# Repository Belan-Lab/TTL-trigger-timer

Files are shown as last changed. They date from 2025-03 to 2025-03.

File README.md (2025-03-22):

General Purpose TTL Timer
===========

TTL trigger timer for working with light sources for animal behavioral tests.

_Protocol written by Valeriia Ustymenko_

## Operation

```
Keypad schematic:

       |3|
|1| |2|    |5|
       |4|
```

__1__ - Emergency stop

__2__ - Time setting mode (1.0s or 0.1s)

__3__ - Increase time

__4__ - Decrease time

__5__ - Timer start/stop

The push button works the same as button 5: 1 press to start, 2 presses to stop.

Press button 5 to reset the timer between measurements.

## Preparation of the system for tests
For optogenetic tests, a system in such configuration was as pictured in the figure below: 

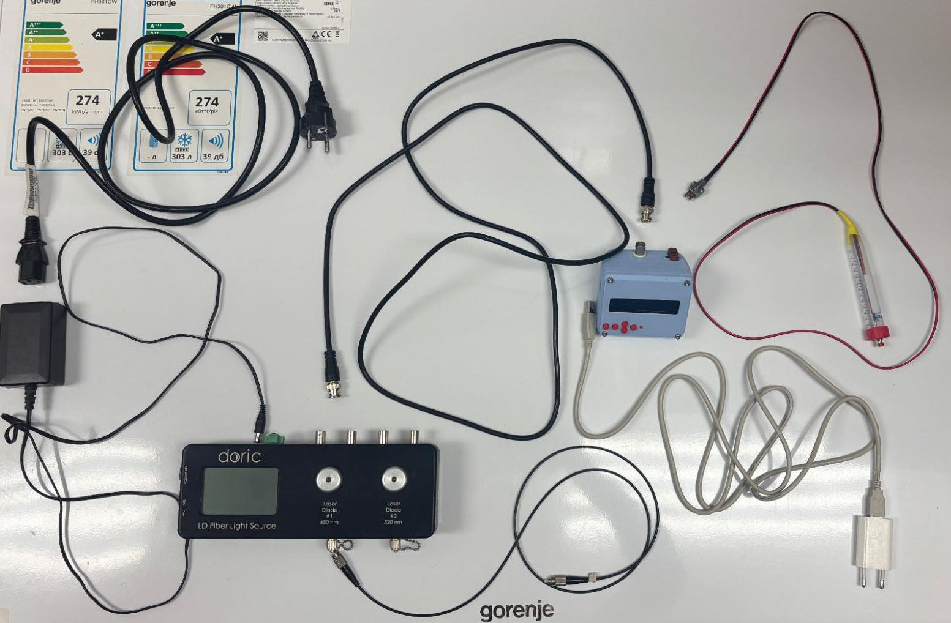
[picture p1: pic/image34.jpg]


*All equipment, needed for optogenetic test*

1. The Doric LDFLS_450/075_520/060 requires a 12V DC power supply. Plug in a cable in the power adapter for the laser diode fiber light source (Doric, LDFLS_450/075_520/060).
2. Locate the 12V DC power input on the back or side of the laser diode fiber light source (Doric, LDFLS_450/075_520/060).
3. Use a BNC cable to connect the TTL signal source to the laser's TTL input for laser diode #1, 450 nm. Rotate the connector to ensure that it is properly secured.

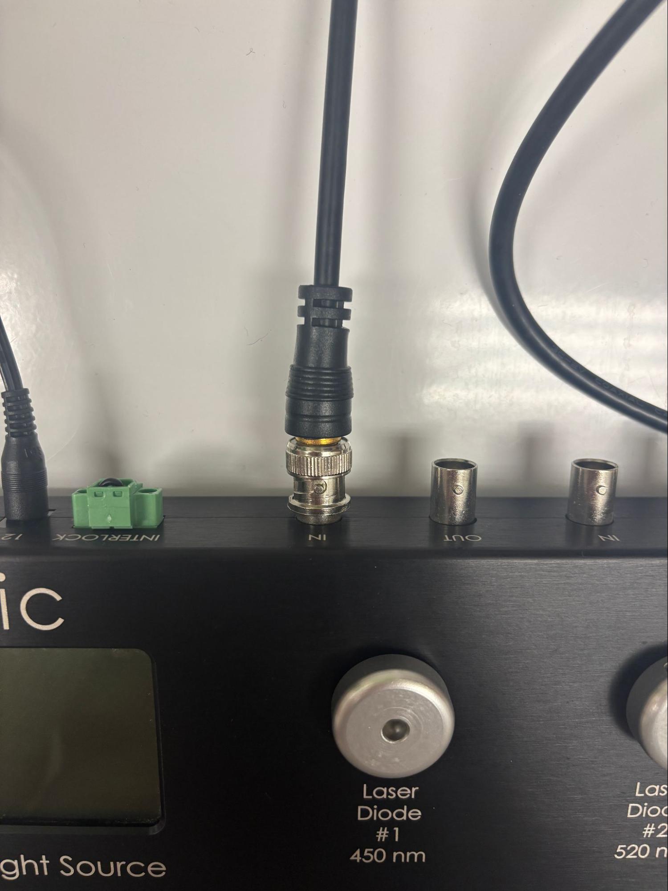
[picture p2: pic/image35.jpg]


4. Check for dust or debris on the fiber tip of optical fiber. Align the fiber connector with the 450 nm laser output port. Gently insert the fiber into the port without forcing it. Rotate clockwise until snug. Do not overtighten, as this can damage the fiber or connector.

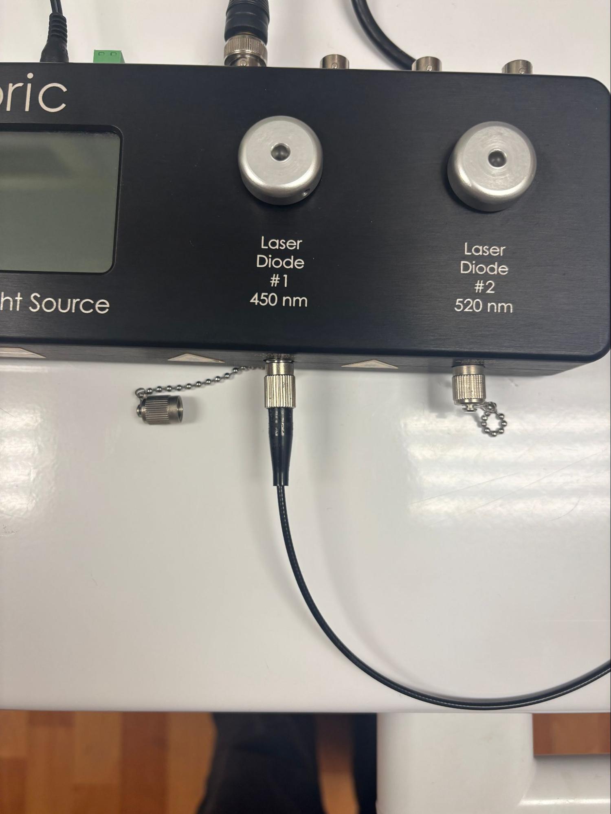
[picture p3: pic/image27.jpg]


__Note: Detailed description of the Doric LDFLS setup is not provided here!__

5. Use a BNC cable to connect the the laser's TTL input for laser diode #1, 450 nm to the TTL timer (Arduino-UNO compatible board with LCD-keypad shield in a very beautiful blue plastic box!). Ensure that you properly secure it by rotating the connector.

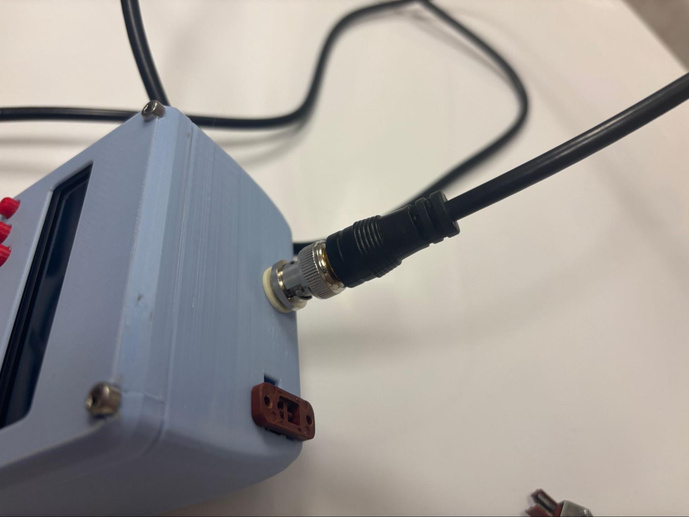
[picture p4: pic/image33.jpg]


6. Plug in a cable that connects the TTL timer  to a push button mounted on a 15 mL centrifuge tube.

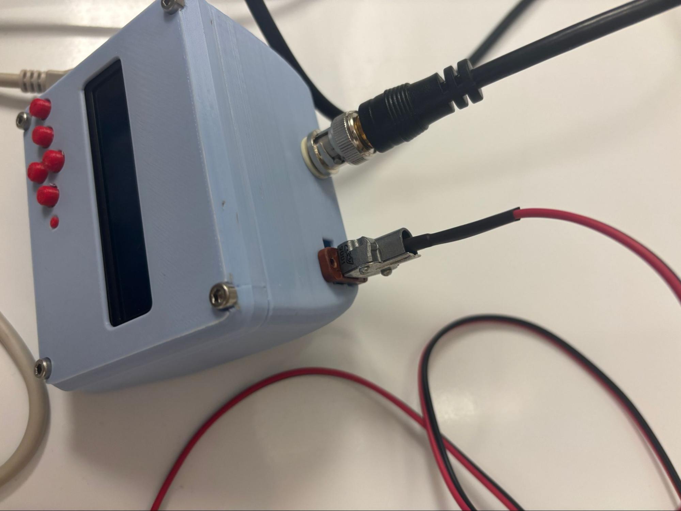
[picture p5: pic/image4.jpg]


7. Plug a DC power adapter into the Arduino’s power jack. The power LED on the Arduino should turn on. Use a regulated power supply to prevent damage. 

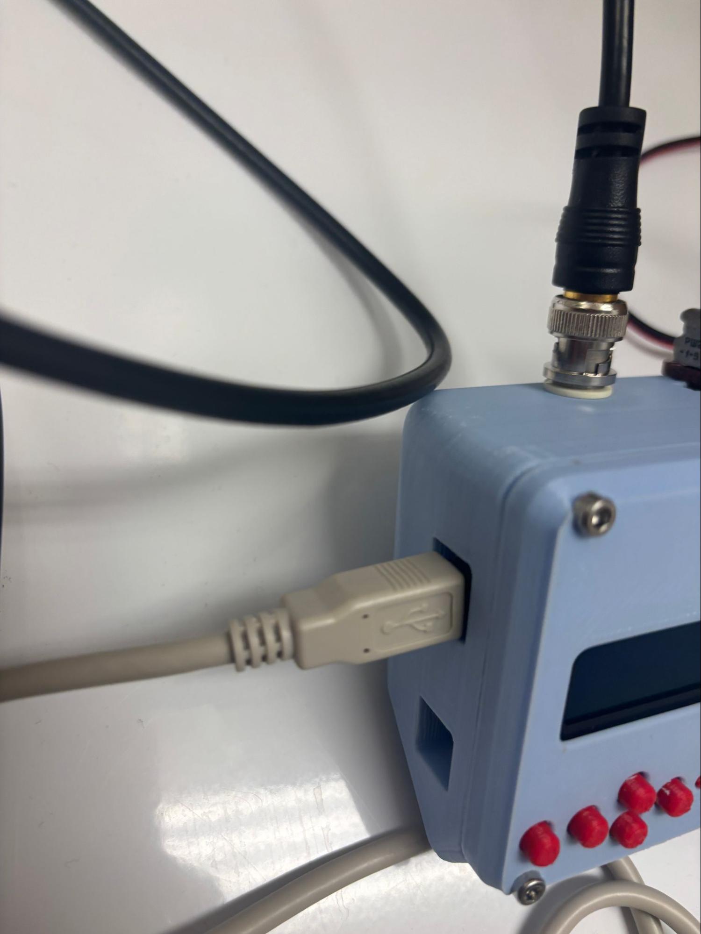
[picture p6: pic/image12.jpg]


8. Set a mode on the TTL timer by pushing the second red button from the left. Two main modes differ in such a way: 1.0 s mode allows to set max explosion time by seconds, and 0.1s mode - 100 milliseconds. 

| 1.0s Mode | 0.1s Mode |
| :---: | :---: |
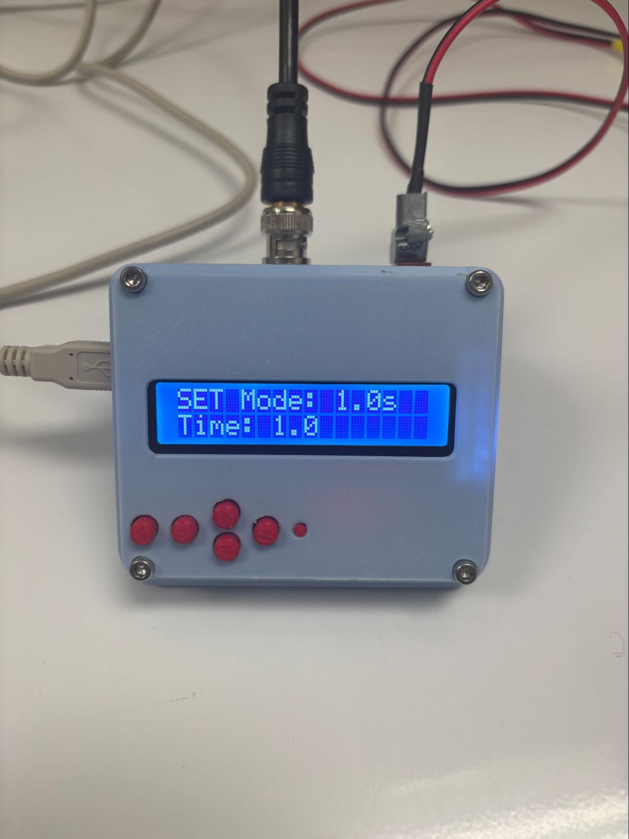
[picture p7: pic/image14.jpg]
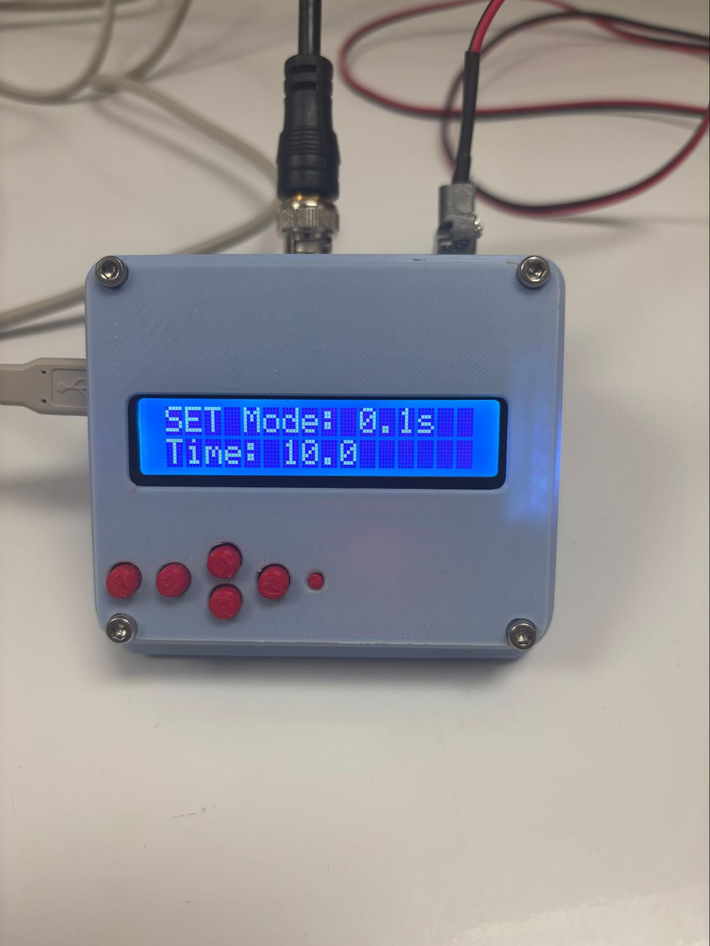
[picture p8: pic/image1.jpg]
|  |  |

10. Set the max time of exposing the hind paw by pushing the third buttons from the left, or middle buttons. We choose max one second exposition to prevent misinterpretation due to thermal stimulation rather than optical activation. The minimal possible exposition is 0.2 seconds.

11. Check the correctness of working of all components of the system by pushing a push button mounted on a 15 mL vial. Do not orient the laser to the eyes!

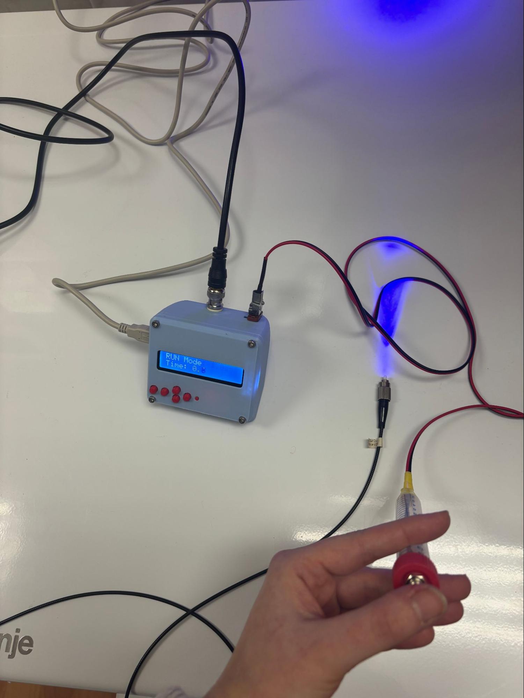
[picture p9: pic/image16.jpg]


-----

## STL Models
The following models from open sources were used in this project:

- [Case for Arduino Uno, LCD Keypad Shield and Stepper Motor Driver by AndreySamokhin on Thingiverse](https://www.thingiverse.com/thing:4194107)
- [Arduino UNO Case](https://www.printables.com/model/244590-arduino-uno-case-with-m3-screwsnuts-and-hexagonal-) and [LCD Keypad Shield Case](https://www.printables.com/model/244258-arduino-lcd-keypad-shield-snap-fit-case) from [@jacek on Printables](https://www.printables.com/@jacek)

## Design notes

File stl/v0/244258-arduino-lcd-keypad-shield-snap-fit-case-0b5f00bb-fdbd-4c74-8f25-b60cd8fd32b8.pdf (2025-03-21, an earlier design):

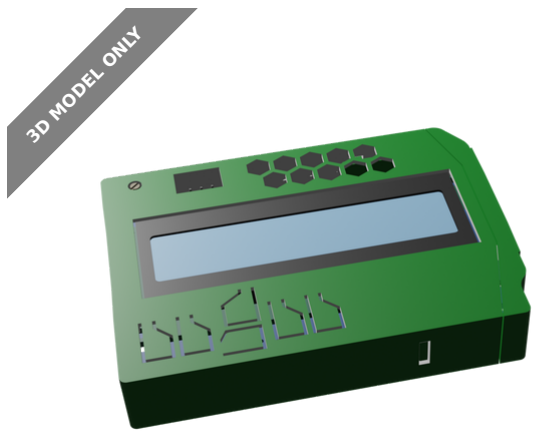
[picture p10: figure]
3D MODEL ONLY

### Summary

Case for Arduino LCD Keypad Shield. Two parts that snap-fit together, integrated buttons.

Hobby & Makers (https://www.printables.com/model?categoryId=48) > Electronics (https://www.printables.com/model?categoryId=52)

Tags: case | shield | arduino | snap | snapfit | lcd | keypad

keypadshield

I made a case for LCD Keypad shield for arduino uno.

The case holds on to the shield itself, so the shield can be detached from arduino togather with case.

The buttons are integrated in the case itself (similar to reset button on prusa printers), so no small parts that fall out during assembly.

Print both parts, orient it flat on the print bed in slicer (front face at the bottom).

Activate supports - activate “Supports on build plate only”.

Works well with my arduino case.

jacek (https://www.printables.com/social/214001/about)

### Arduino LCD

## Keypad Shield

### Snap-Fit case

VIEW IN BROWSER (https://www.printables.com/model/244258-arduino-lcd-keypad-shield-snap-fit-case)

updated 18. 7. 2022 | published 18. 7. 2022

## Model files

### License

This work is licensed under a
Creative Commons (4.0 International License)

Attribution (http://creativecommons.org/licenses/by/4.0/)

✖ | Sharing without ATTRIBUTION
✔ | Remix Culture allowed
✔ | Commercial Use
✔ | Free Cultural Works
✔ | Meets Open Definition

lcd_keypad_shield_case_bighalf_v2.stl

lcd_keypad_shield_case_cover_v2.stl

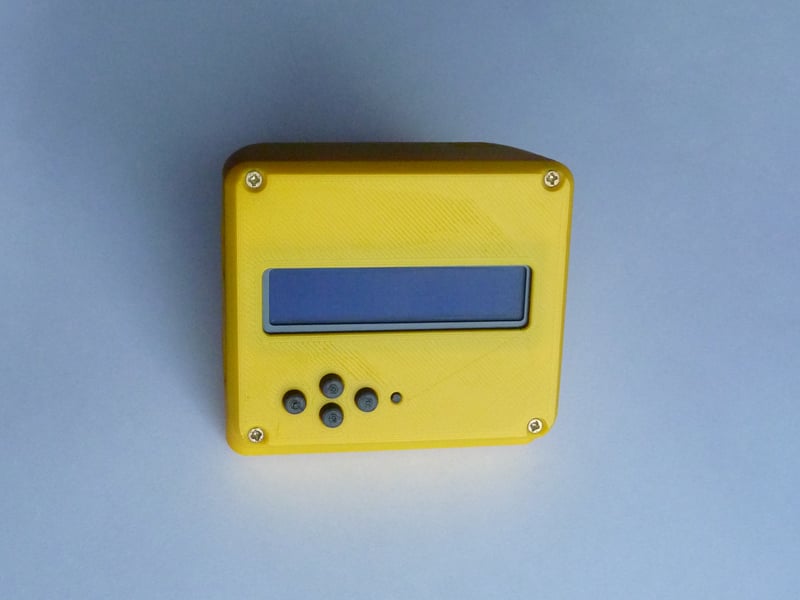
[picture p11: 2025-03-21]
stl/v2/images/fig5.jpg

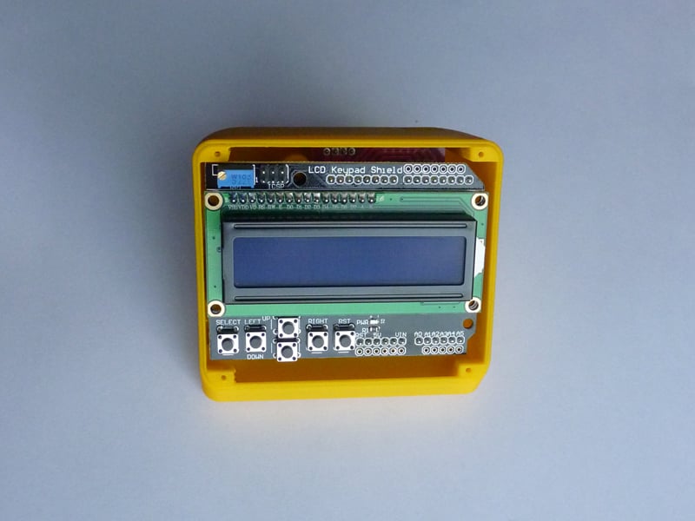
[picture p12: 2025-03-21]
stl/v2/images/fig4.jpg

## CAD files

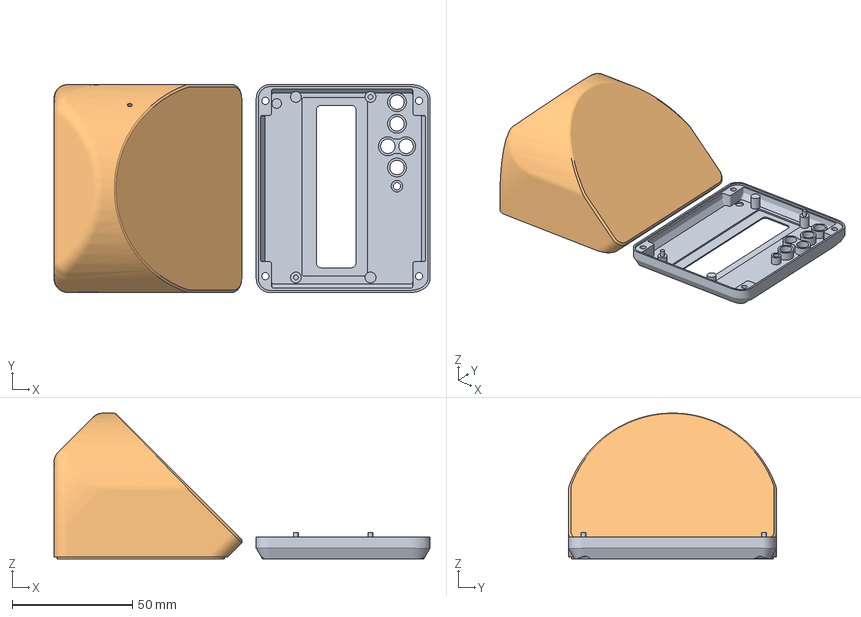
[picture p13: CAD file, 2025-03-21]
stl/v2/caseСover_6buttons.3mf
156.2 x 86.5 x 60.6 mm
caseСover_6buttons.stl
caseBase.stl

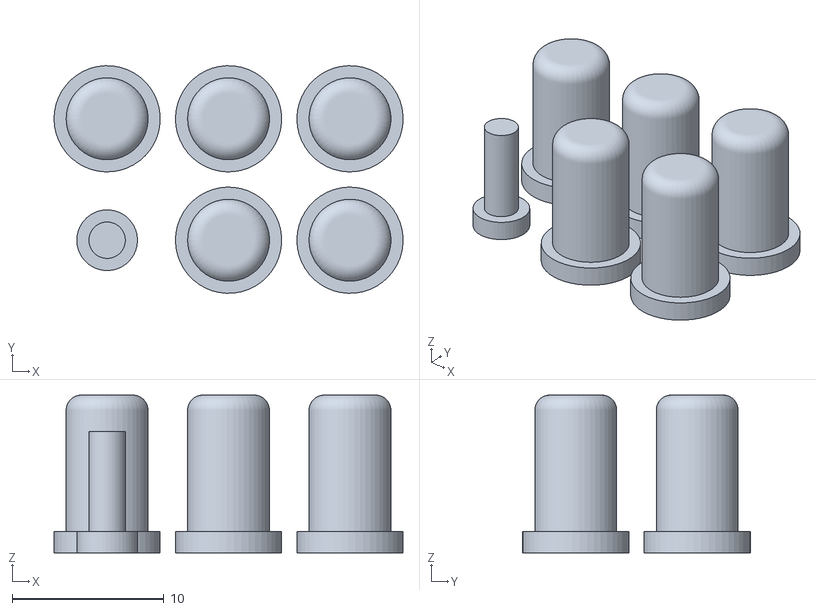
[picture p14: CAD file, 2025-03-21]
stl/v2/files/caseButtons_6buttons.stl
23.0 x 15.0 x 10.4

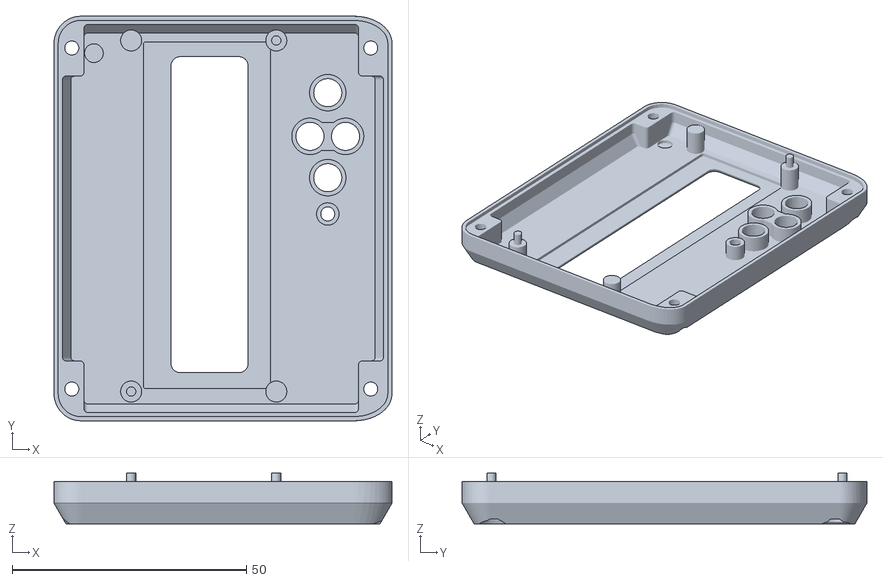
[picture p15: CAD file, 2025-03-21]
stl/v2/files/caseСover.stl
72.2 x 86.5 x 10.9

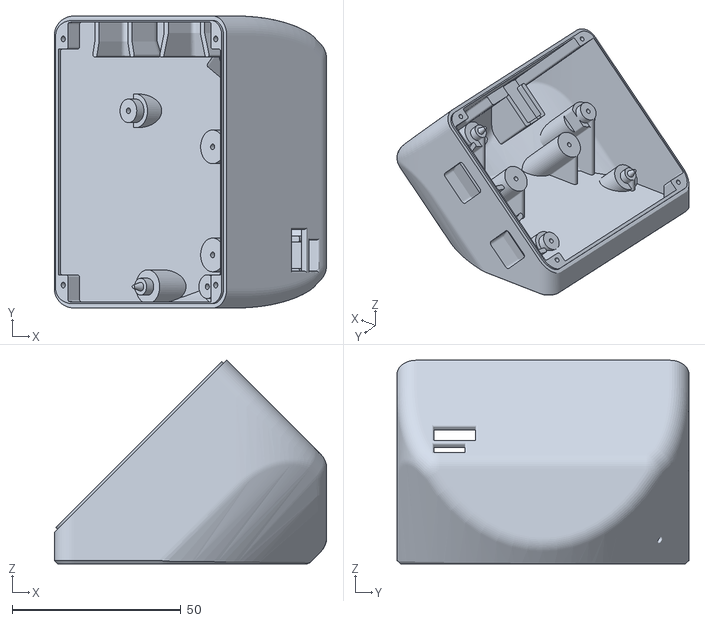
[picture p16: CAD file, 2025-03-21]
stl/v2/files/caseBase.stl
80.7 x 86.5 x 60.3

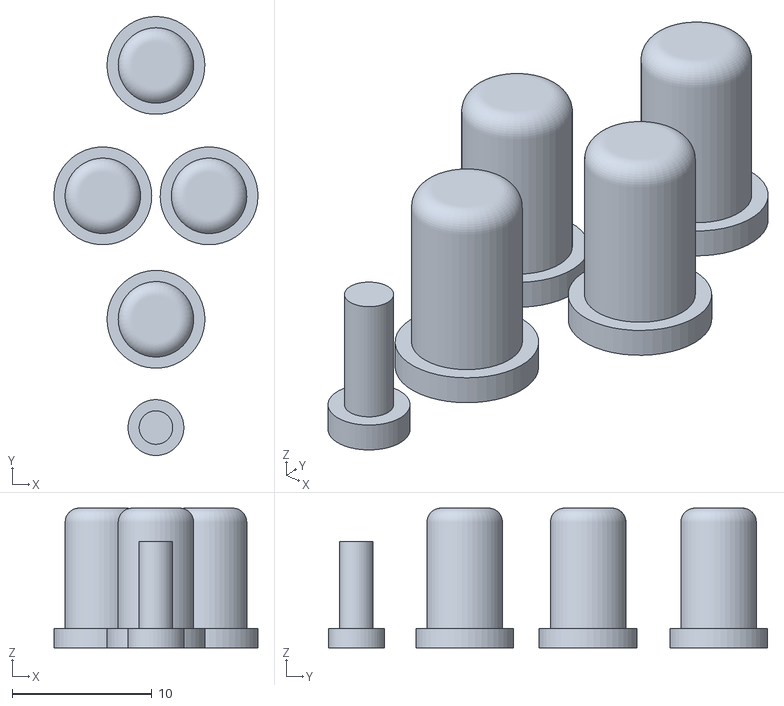
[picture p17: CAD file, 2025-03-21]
stl/v2/files/caseButtons.stl
14.6 x 31.4 x 10.0

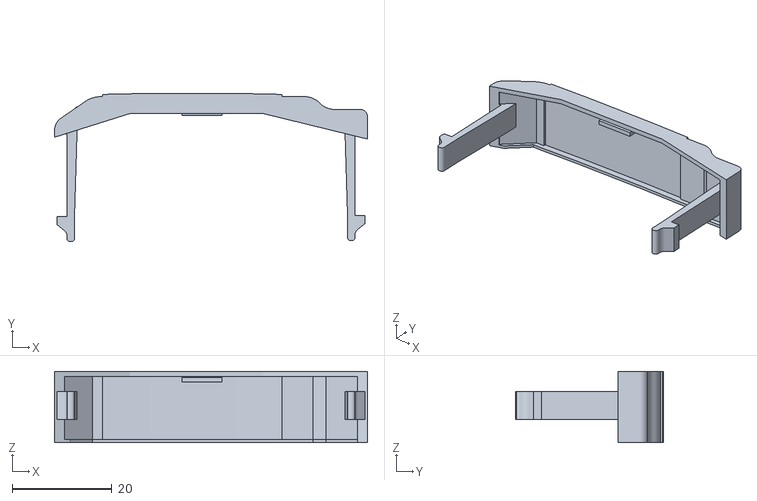
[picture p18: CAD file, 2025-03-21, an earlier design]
stl/v0/lcd_keypad_shield_case_cover_v2.stl
62.7 x 29.7 x 14.3

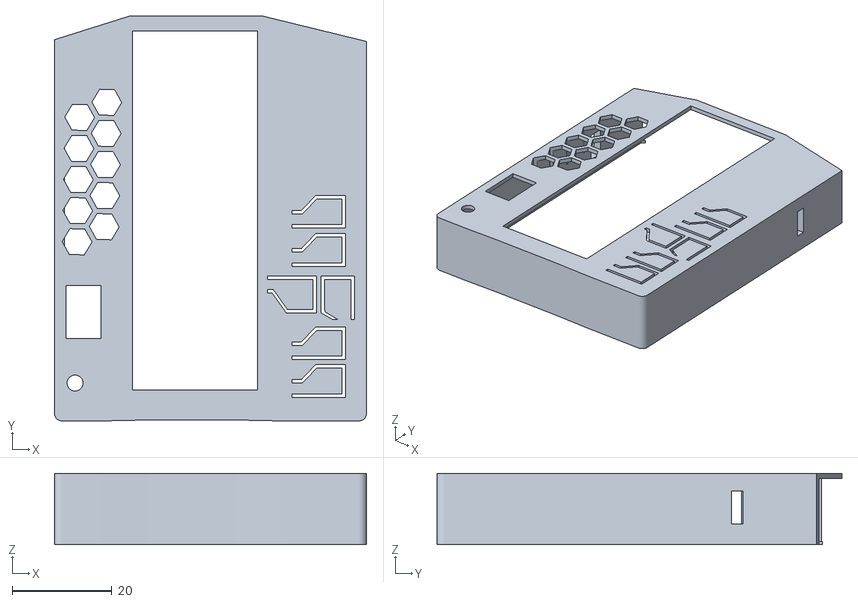
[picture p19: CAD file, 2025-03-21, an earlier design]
stl/v0/lcd_keypad_shield_case_bighalf_v2.stl
62.7 x 81.3 x 14.3

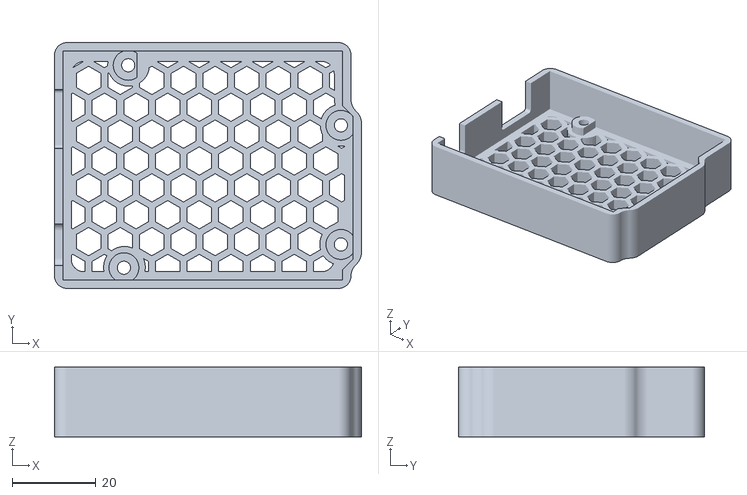
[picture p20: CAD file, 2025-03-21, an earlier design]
stl/v0/hexcase_v2.stl
73.2 x 58.7 x 16.6

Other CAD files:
stl/v2/files/caseСover_6buttons.stl

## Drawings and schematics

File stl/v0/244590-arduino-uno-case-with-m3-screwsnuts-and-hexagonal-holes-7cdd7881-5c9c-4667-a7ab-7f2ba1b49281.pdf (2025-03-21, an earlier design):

## Arduino UNO case

## with m3 screws/

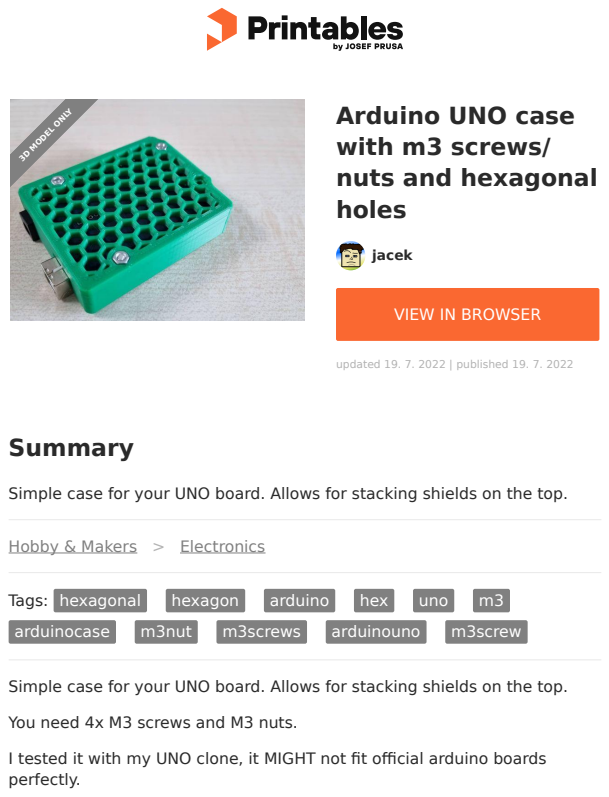
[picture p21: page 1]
Summary; Tags: hexagonal; hexagon; arduino; hex; uno; arduinocase; m3nut; m3screws; arduinouno; m3screw; jacek; updated 19. 7. 2022 | published 19. 7. 2022; 3D MODEL ONLY

nuts and hexagonal
holes

VIEW IN BROWSER (https://www.printables.com/model/244590-arduino-uno-case-with-m3-screwsnuts-and-hexagonal-)

Simple case for your UNO board. Allows for stacking shields on the top.

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

You need 4x M3 screws and M3 nuts.

I tested it with my UNO clone, it MIGHT not fit official arduino boards
perfectly.

# Model files

## License

This work is licensed under a
Creative Commons (4.0 International License)

Attribution (http://creativecommons.org/licenses/by/4.0/)

✖ | Sharing without ATTRIBUTION
✔ | Remix Culture allowed
✔ | Commercial Use
✔ | Free Cultural Works
✔ | Meets Open Definition

hexcase_v2.stl

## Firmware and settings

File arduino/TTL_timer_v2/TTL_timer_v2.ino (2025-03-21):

#include <LiquidCrystal.h>

// Define button codes based on LCD Keypad Shield analog reading
#define btnRIGHT   1
#define btnUP      2
#define btnDOWN    3
#define btnLEFT    4
#define btnSELECT  5
#define btnNONE    0

// Initialize the LCD (RS, E, D4, D5, D6, D7)
// Default for Arduino LCD Keypad Shield: RS = 8, E = 9, D4 = 4, D5 = 5, D6 = 6, D7 = 7.
LiquidCrystal lcd(8, 9, 4, 5, 6, 7);

// Analog pin for reading keypad buttons.
const int analogPin = A0;

// Digital output pin used for triggering an external device.
const int triggerPin = 13;

// Digital input pin for the additional RUN/STOP button.
const int runStopButtonPin = 12;

// Timer variables (stored in tenths of a second)
int timerSet = 100;    // Default value: 10.0 sec (i.e. 100 tenths)
int timeElapsed = 0;   // Elapsed time in tenths of sec

// State variables
bool timerRunning = false;  // TRUE: RUN mode; FALSE: SET mode
bool runStopped = false;    // TRUE: timer зупинено за допомогою кнопки на PIN 12
bool isTenthsMode = false;  // FALSE: Seconds Mode (increment by 10 tenths), TRUE: 0.1 s Mode (increment by 1 tenth)

// Timing control (non-blocking)
unsigned long previousMillis = 0;
const unsigned long interval = 100;  // 0.1 sec interval (100 ms)

// Debounce variables
unsigned long lastButtonPress = 0;
const unsigned long debounceDelay = 200;  // 200 ms debounce period

// Функція для зчитування кнопок з LCD Keypad Shield через аналоговий вхід
int read_LCD_buttons() {
  int adc_key_in = analogRead(analogPin);
  if (adc_key_in > 1000) return btnNONE;
  if (adc_key_in < 50)   return btnRIGHT;
  if (adc_key_in < 250)  return btnUP;
  if (adc_key_in < 450)  return btnDOWN;
  if (adc_key_in < 650)  return btnLEFT;
  if (adc_key_in < 850)  return btnSELECT;
  return btnNONE;
}

// Функція аварійної зупинки таймера (SEL), скидання лічильника та оновлення дисплея
void emergencyStop() {
  timerRunning = false;
  runStopped = false;
  timeElapsed = 0;
  digitalWrite(triggerPin, LOW);
  lcd.clear();
  lcd.setCursor(0, 0);
  lcd.print("EMERG STOP");
  lcd.setCursor(0, 1);
  lcd.print("Time: 0.0");
  delay(1000);  // невелика затримка для демонстрації повідомлення
}

void setup() {
  lcd.begin(16, 2);
  lcd.clear();

  pinMode(triggerPin, OUTPUT);
  digitalWrite(triggerPin, LOW);

  pinMode(runStopButtonPin, INPUT_PULLUP);  // використання внутрішнього pull-up резистора
  
  // Відображення початкового повідомлення в SET Mode
  lcd.clear();
  lcd.setCursor(0, 0);
  lcd.print("TTL Triger Timer");
  lcd.setCursor(3, 1);
  lcd.print("DoMB 2025");
  delay(2000);
}

void loop() {
  unsigned long currentMillis = millis();
  int lcdButton = read_LCD_buttons();
  bool runStopButtonState = (digitalRead(runStopButtonPin) == HIGH);

  // SET Mode: Налаштування таймера (timer не працює та не знаходиться у режимі зупинки)
  if (!timerRunning && !runStopped) {
    // Обробка кнопок з LCD, якщо пройшло достатньо часу для дебаунсу
    if (lcdButton != btnNONE && (currentMillis - lastButtonPress > debounceDelay)) {
      if (lcdButton == btnUP) {
        // Збільшення часу: на 1.0 сек у Seconds Mode або на 0.1 сек у 0.1 s Mode
        if (isTenthsMode) {
          timerSet++;
        } else {
          timerSet += 10;
        }
      } else if (lcdButton == btnDOWN) {
        // Зменшення часу, не менше нуля
        if (isTenthsMode && timerSet > 0) {
          timerSet--;
        } else if (!isTenthsMode && timerSet >= 10) {
          timerSet -= 10;
        }
      } else if (lcdButton == btnLEFT) {
        // Перемикання режиму коригування: Seconds Mode <-> 0.1 s Mode
        isTenthsMode = !isTenthsMode;
      } else if (lcdButton == btnRIGHT) {
        // Початок таймера (RUN Mode) при натисканні кнопки RIGHT
        timerRunning = true;
        runStopped = false;
        timeElapsed = 0;
        previousMillis = currentMillis;
        digitalWrite(triggerPin, HIGH);
      }
      lastButtonPress = currentMillis;
    }
    // Також, якщо натиснуто кнопку на PIN 12, стартуємо RUN Mode
    if (runStopButtonState && (currentMillis - lastButtonPress > debounceDelay)) {
      timerRunning = true;
      runStopped = false;
      timeElapsed = 0;
      previousMillis = currentMillis;
      digitalWrite(triggerPin, HIGH);
      lastButtonPress = currentMillis;
    }
    
    // Оновлення дисплея в SET Mode (час відображається з точністю до 0.1 сек)
    lcd.clear();
    lcd.setCursor(0, 0);
    lcd.print(isTenthsMode ? "SET Mode: 0.1s" : "SET Mode: 1.0s");
    lcd.setCursor(0, 1);
    lcd.print("Time: ");
    int sec = timerSet / 10;
    int tenth = timerSet % 10;
    lcd.print(sec);
    lcd.print(".");
    lcd.print(tenth);
    delay(100);
  }
  // RUN Mode: Лічильник працює від 0.0 до заданого часу
  else if (timerRunning) {
    // Аварійна зупинка кнопкою SEL: скидання таймера та завершення роботи
    if (lcdButton == btnSELECT && (currentMillis - lastButtonPress > debounceDelay)) {
      emergencyStop();
      lastButtonPress = currentMillis;
      return;  // вихід з функції loop для негайного оновлення
    }
    // Звичайна зупинка кнопкою на PIN 12: зупинення таймера, але збереження пройденого часу
    if (runStopButtonState && (currentMillis - lastButtonPress > debounceDelay)) {
      timerRunning = false;
      runStopped = true;
      digitalWrite(triggerPin, LOW);
      lastButtonPress = currentMillis;
    }
    
    // Неперервний відлік часу з використанням millis() кожні 0.1 секунди
    if (currentMillis - previousMillis >= interval) {
      previousMillis += interval;
      timeElapsed++;
      if (timeElapsed >= timerSet) {  // досягнення встановленого значення часу
        timerRunning = false;
        digitalWrite(triggerPin, LOW);
      }
    }
    
    // Оновлення дисплея в RUN Mode (відображення пройденого часу з точністю 0.1 сек)
    lcd.clear();
    lcd.setCursor(0, 0);
    lcd.print("RUN Mode");
    lcd.setCursor(0, 1);
    int secElapsed = timeElapsed / 10;
    int tenthElapsed = timeElapsed % 10;
    lcd.print("Time: ");
    lcd.print(secElapsed);
    lcd.print(".");
    lcd.print(tenthElapsed);
  }
  // Режим зупинки (STOPPED Mode), коли таймер зупинено кнопкою на PIN 12 (RUN/STOP)
  else if (runStopped) {
    lcd.clear();
    lcd.setCursor(0, 0);
    lcd.print("RUN STOP");
    lcd.setCursor(0, 1);
    int secElapsed = timeElapsed / 10;
    int tenthElapsed = timeElapsed % 10;
    lcd.print("Time: ");
    lcd.print(secElapsed);
    lcd.print(".");
    lcd.print(tenthElapsed);
    delay(100);
    // Натискання будь-якої кнопки повертає нас до SET Mode
    if (lcdButton != btnNONE && (currentMillis - lastButtonPress > debounceDelay)) {
      runStopped = false;
      timerRunning = false;
      lastButtonPress = currentMillis;
    }
  }
}
